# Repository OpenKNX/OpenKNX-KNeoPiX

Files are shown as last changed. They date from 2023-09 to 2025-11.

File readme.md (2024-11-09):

# OpenKNX - KNeoPix

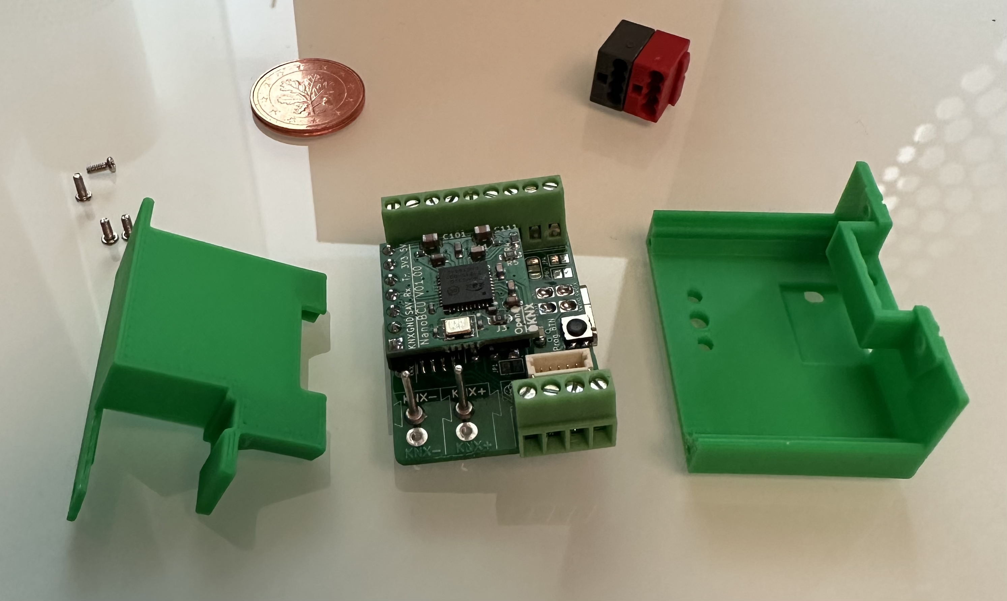
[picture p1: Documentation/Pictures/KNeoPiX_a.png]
KNEOPIX


## Preliminary Information about OpenKNX KNeoPix

The **OpenKNX KNeoPix** is a hardware solution designed specifically for DIY (Do It Yourself) projects in the realm of building automation and intelligent networking. Created for enthusiasts and hobbyists, it allows users to develop creative KNX automation solutions. **KNeoPix** is a DIY product and does not come with any warranties. This means that users are responsible for assembly, configuration, and operation. **KNeoPix** is fully compatible with the **openKNX** software platform, ensuring seamless integration within the **OpenKNX** ecosystem.

Additionally, **KNeoPix** supports LED control, including **WS2815**, **SM16704**, and **SK6812** addressable LEDs, with voltage ranges from **3.3V to 24V**. Two isolated IOs are dedicated for this LED control, allowing for smooth management of lighting systems. Moreover, **6 direct IOs** are available for additional control purposes, making **KNeoPix** a versatile solution for various applications in building automation.

KNEOPIX

### Hardware

The hardware of **KNeoPix** is based on either the [XIAO RP2040](https://www.seeedstudio.com/XIAO-RP2040-v1-0-p-5026.html) or the [XIAO SAMD21](https://www.seeedstudio.com/Seeeduino-XIAO-Arduino-Microcontroller-SAMD21-Cortex-M0+-p-4426.html) microcontroller. It works in conjunction with the [OpenKNX BCU](https://github.com/OpenKNX/OpenKNX/wiki/NanoBCU) platform, enabling a broad range of applications in building KNX automation and smart home networking.

### Power Supply

A standout feature of **KNeoPix** is its flexible power supply options. It can be powered directly from the **KNX bus voltage** at either **3.3V** or **5V**, facilitating straightforward integration into KNX-based systems. Additionally, it can be powered via an external voltage source ranging from **6V to 24V**. This flexibility allows **KNeoPix** to accommodate a wide variety of installation scenarios and adapt to diverse system requirements.

### Galvanic Isolation

When powered by an external voltage source, **KNeoPix** offers **galvanic isolation** from the KNX bus. This feature ensures a safe and reliable integration into KNX networks by protecting against electrical disturbances, enhancing overall system stability.

### Inputs and Outputs (I/Os)

**KNeoPix** provides a total of **6 direct** and **2 isolated** inputs and outputs (I/Os), offering versatile application possibilities. Its primary function is to control **RGB LEDs** via the two isolated I/Os, enabling captivating lighting effects for smart buildings. The six direct I/Os can be used for additional control tasks, making **KNeoPix** an incredibly flexible tool for various building automation purposes.

### Voltage Options

**KNeoPix** supports multiple voltage configurations, operating both the external voltage at **3.3V/5V** as a direct power supply, or using **6V to 24V** as a variable power supply. This provides maximum flexibility in configuring and deploying the hardware to meet specific project requirements.

### Pin Compatibility

Another key feature of **KNeoPix** is its **pin compatibility** with other microcontrollers in the **XIAO series**, such as the [XIAO ESP32C3](https://www.seeedstudio.com/Seeed-XIAO-ESP32C3-p-5431.html) and [XIAO ESP32S3](https://www.seeedstudio.com/XIAO-ESP32S3-p-5627.html). This compatibility enhances its versatility, allowing users to take advantage of existing hardware for their projects and easily integrate with other XIAO boards.

## KNeoPiX Documentation

This documentation provides details about the KNeoPiX board and its components, including jumper settings, connections, power source options, and other related information.

### Available IOs and Descriptions i.e. for XIAO RP2040 and SAMD21

|  **IO Number**  | **<a href="Documentation/External/XIAO_RP2040_v1/XIAO RP2040 v1.22 SCH.pdf" target="_blank">XIAO RP2040 Pins</a>** | **<a href="Documentation/External/XIAO-SAMD21_V1/Seeeduino XIAO_v1.0_SCH_191112.pdf" target="_blank">SAMD21 Pins</a>** | **Description** |
| :---: | :--- | :--- | :--- |
| D0** | GPIO0 / A0 | GPIO0 / A0 | **Non-isolated IO - Prog Button** |
| **D1** | GPIO1 / A1 | GPIO1 / A1 | **Non-isolated IO** |
| **D2** | GPIO2 / A2 | GPIO2 / A2 | **Non-isolated IO** |
| **D3** | GPIO3 / A3 | GPIO3 / A3 | **Non-isolated IO** |
| **D4** | GPIO4 / SDA | GPIO4 / SDA | **Isolated IO - NEO DATA0 OUT** |
| **D5** | GPIO5 / SCL | GPIO5 / SCL | **Isolated IO - NEO DATA1 OUT** |
| **D6** | GPIO6 / TX | GPIO6 / TX | **Isolated IO - to KNX RX** |
| **D7** | GPIO7 / RX | GPIO7 / RX | **Isolated IO - to KNX TX** |
| **D8** | GPIO8 / SCK | GPIO8 / SCK | **Non-isolated IO** |
| **D9** | GPIO9 / MISO | GPIO9 / MISO | **Non-isolated IO** |
| **D10** | GPI010 / MOSI | GPI010 / MOSI | **Non-isolated IO** |
| **OnBoard LED** | GPIO25 / RGB BLUE | GPIO11 / BLUE | **USER LED** |
| **OnBoard LED** | GPIO16 / RGB GREEN | GPIO12 / BLUE | **USER LED** |
| **OnBoard LED** | GPIO17 / RGB RED | GPIO13 / YELLOW | **USER LED** |
| NEOPIXEL | GPIO12 / RGB NEOPIXEL (GPIO11 / POWER) | N/A | **Onboard NEOPIXEL RGB LED** |
| **SWD** | SWDIO, SWCLK, RST | SWDIO, SWCLK, RST | **Debugging Interface** |
| **Prog Button** | GPIO26 (RUN) | PA15 (RUN) | **Program Button Interface** |

### 1. KNX Connection and Isolator

The KNX connection and isolator section manages communication with the KNX bus. The relevant components in this section include:

- **KNX+**: KNX positive voltage input.
- **KNX-**: KNX negative voltage input.
- **GN1**: KNX communication ground.
- **ISO_IN** / **ISO_OUT**: Isolated I/O pins for communication between the KNX module and the rest of the circuit.

### 2. Digital Isolator for GPIO4 & GPIO5

This section uses the **ADuM1250** IC to isolate GPIO pins 4 and 5. The jumpers associated with this section are:

- **R1, R2**: 0 Ohm jumpers.
- **C4**: Capacitor for filtering.
- **ISO_DATA_OUT**: Isolated data output.
- **ISO_DATA_IN**: Isolated data input.

### 3. Connections

#### 3.1 Screw Terminal - Isolated I/Os

- Provides isolated input/output connections.
- **J4**: Terminal block for isolated I/O pins.

#### 3.2 Screw Terminal - Non-Isolated I/Os

- For non-isolated communication.
- **J3**: Terminal block for non-isolated I/Os.

#### 3.3 Prog Button

- **SW1**: Programming button to interact with the microcontroller.

#### 3.4 OpenKNX Debug

- Debug connections to monitor KNX communication signals.

### 4. Jumpers - Power Source Selection

#### 4.1 JP1 (GND KNX Voltage Input)

- Jumper for KNX GND voltage input.

#### 4.2 JP2 (3V3 KNX Voltage Input)

- Jumper to select **3.3V** KNX voltage input.

#### 4.3 JP5 (Select U2 and Input Voltage)

- Jumper to select voltage source:
  - **Bridge 1+2** for **3V3**.
  - **Bridge 2+3** for **5V**.

#### 4.4 JP6 (5V KNX Voltage Input)

- Jumper for **5V** KNX voltage input.

### 5. External VCC Input

The external VCC input allows the board to be powered by an external DC power source (6-24V).

- **JP3**: Select between **3.3V** or **5V** input from external power.
- **U2 (LM2937IMP-3.3/5.0)**: Regulator to convert external voltage to either **3.3V** or **5V**.
- **JP5**: Used to select the desired output voltage.
  - **Bridge 1+2** for **3.3V** output.
  - **Bridge 2+3** for **5V** output.

### 7. Material

- KNeoPix PCB can be Ordered from the [OpenKNX-Community](https://github.com/OpenKNX/OpenKNX/wiki/Device-Overview) or you can manufacture (i.e.: [jlcpcb.com](https://jlcpcb.com/https:/) ) your own PCB using the BOM/CPL and GERBER from [Release Folder](Hardware/Release/v1.3/)

  | Kommentar                         | Designator    | Footprint                                                                                |
  | ----------------------------------- | --------------- | ------------------------------------------------------------------------------------------ |
  | 100nF                             | C1,C2, C5, C6 | C 0805 2012 Metric                                                                       |
  | 100nF 25V                         | C3            | C_0805 2012 Metric                                                                       |
  | 10µf 16V                         | C4            | C 0805 2012 Metric                                                                       |
  | OpenKNX_BCU                       | GN1           | [NanoBCU](https://github.com/OpenKNX/OpenKNX/wiki/NanoBCU) (Optional: LowProfile )       |
  | ADuM1201AR / ADum1250             | U3            | SOIC-8 3.9x4.9mm P1.27mm                                                                 |
  | Prog BTN                          | SW1           | SW Push 1P1T NO CK KMR2                                                                  |
  | Seeeduino XIAO                    | U1            | [Seeeduino XIAO](https://www.seeedstudio.com/xiao-series-page) (Tested: RP2040 / SAMD21) |
  | LM2937IMP-3.3 / 5.0               | U2 - Optional | SOT-223-3 Tab Pin2                                                                       |
  | ADum1250                          | U4 - Optional | SOIC-8 3.9x4.9mm P1.27mm                                                                 |
  | SMAJ40CA-13-F                     | D3 - Optional | D_SMA                                                                                    |
  | Screw Terminal - Isolated IOs     | J4 - Optional | Terminal Block Phoenix MPT-0,5-4-2.54 1x04 P2.54mm Horizontal                            |
  | Screw Terminal - Non Isolated IOs | J3 - Optional | TerminalBlock Phoenix MPT-0,5-9-2.54 1x09 P2.54mm Horizontal                             |
  | Conn_01x05                        | J5 - Optional | JST SH BM05B-SRSS-TB 1x05-1MP P1.00mm Vertical                                           |
  | Conn_01x05                        | J6 - Optional | PinHeader 1x05 P1.00mm Vertical                                                          |

The [Schematic](/Documentation/Schematic_v1.3.pdf) provides all related and also additional Informations!

### 8. Soldering

The final soldering targets (Designators) are all documented on the PCB. You must align the board with solder pads from XIAO to ensure that the board is properly aligned with XIAO.
It is best to use the markings provided for this purpose and the solder pap holes, which can then be seen on the top of the circuit board. It is best to use an adhesive strip to fix the circuit board and XIAO in place.

- Soldering sequence: Start with the smallest components (SMD Capacitors, ICs, passivce throuch-hole, connectors, transsistors, ...)
  Here the Soldering Example, from left to right.

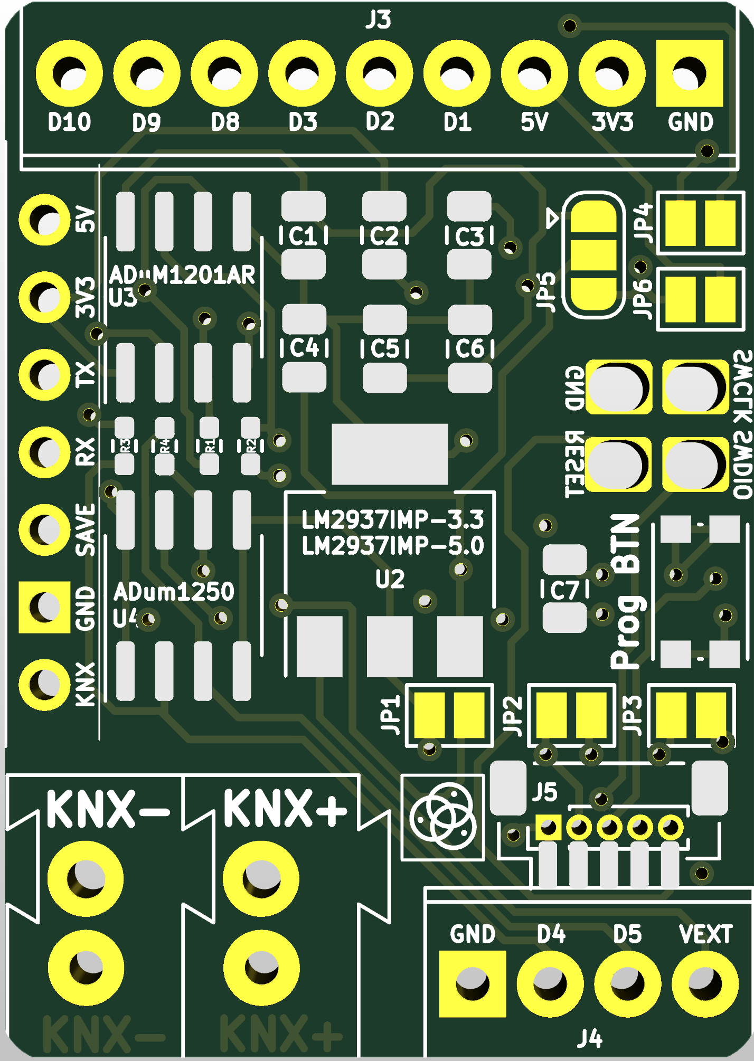
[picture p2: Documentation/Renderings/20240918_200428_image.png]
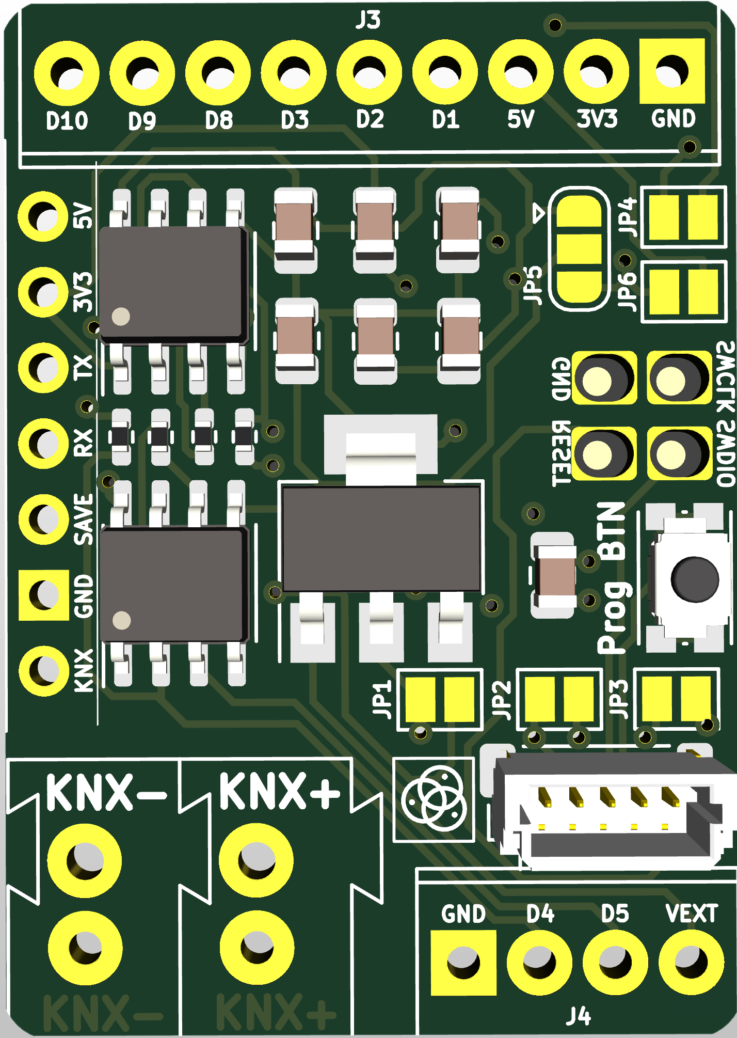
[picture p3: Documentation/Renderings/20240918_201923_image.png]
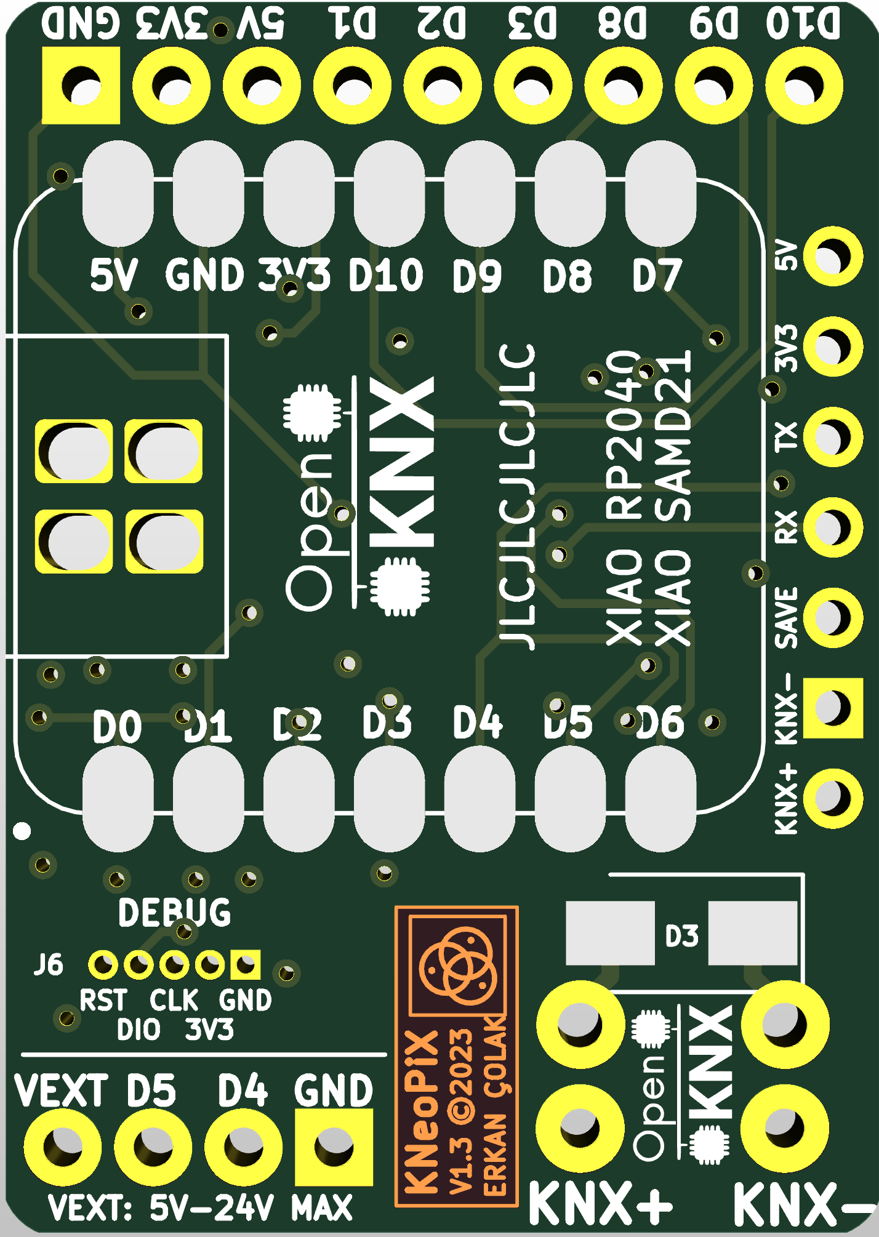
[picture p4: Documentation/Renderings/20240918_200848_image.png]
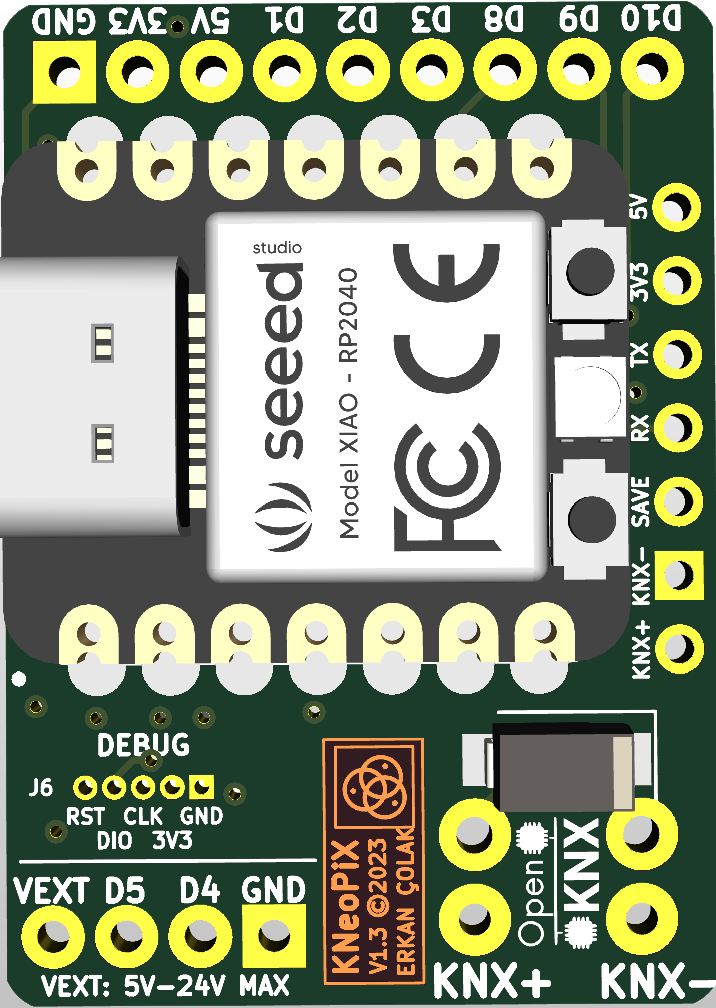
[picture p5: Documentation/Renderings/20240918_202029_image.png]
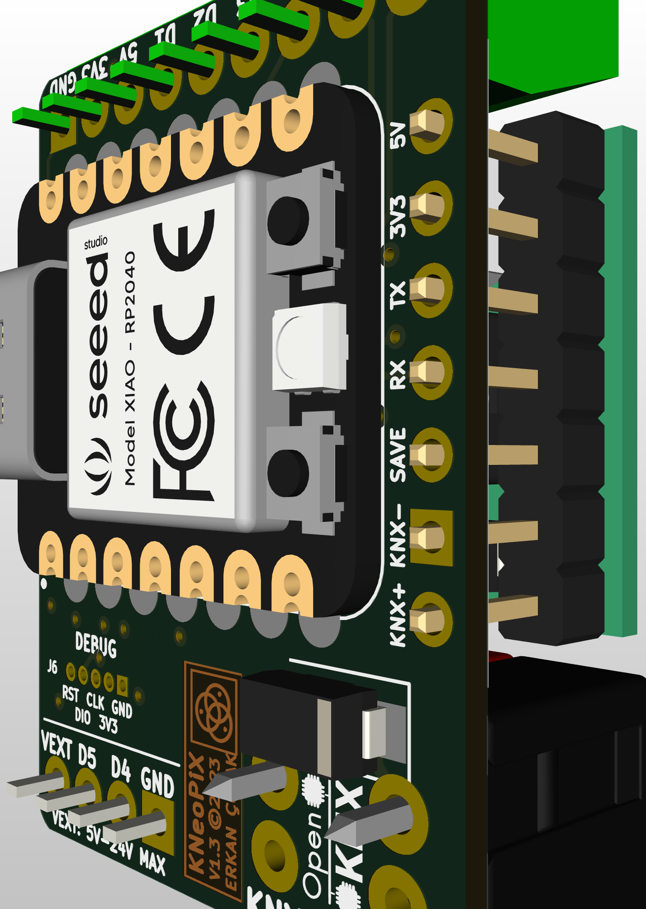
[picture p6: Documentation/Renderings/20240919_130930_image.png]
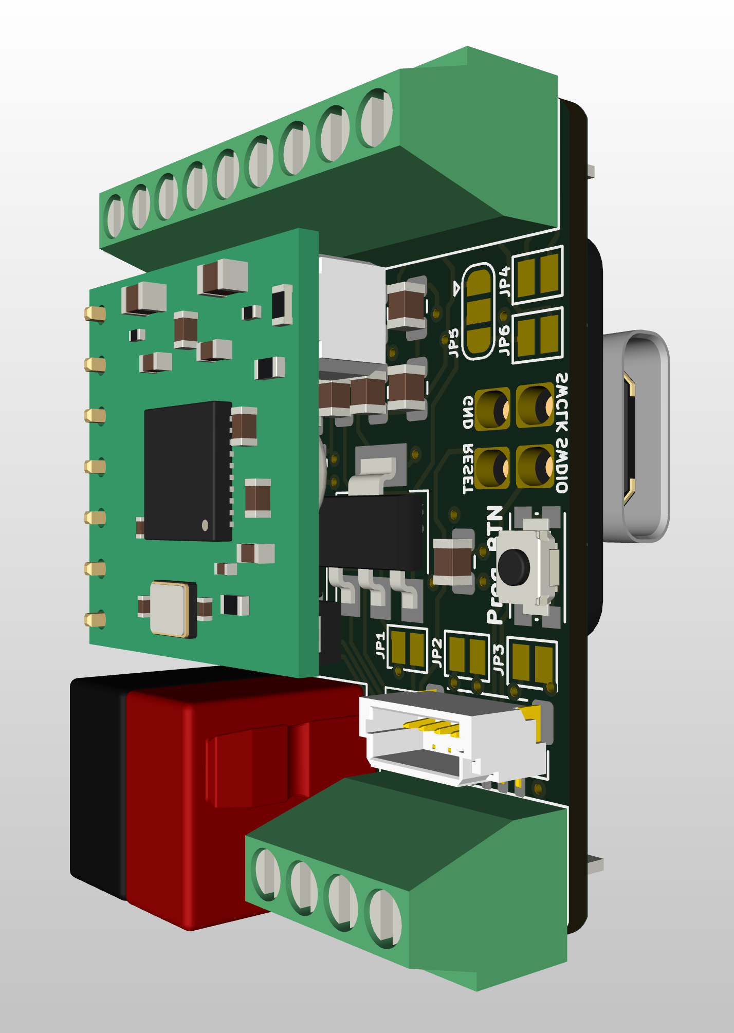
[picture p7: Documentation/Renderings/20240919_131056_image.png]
  -      
  - To solder the debug interface connections, you should solder the designated holes. Be careful not to create any solder bridges between RESET, GND, SWDIO, and SWCLK. These connections are optional.

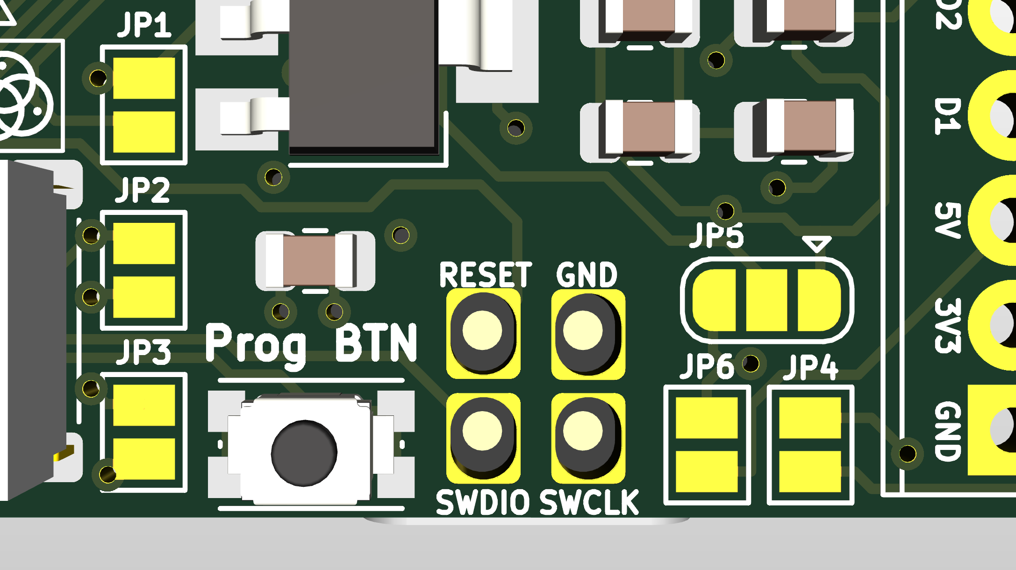
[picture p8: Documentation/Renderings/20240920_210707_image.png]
    
- Finish by soldering larger components ( screw terminals).
- Check all solder joints for proper connections and make sure no short circuits are present.

### 9. Jumper Soldering / Power Source Selection Guide

| **Use Case** | **Jumpers to Bridge** | **Additional Information** |
| --- | --- | --- |
| **KNX 3V3 ONLY** | JP1 → Bridge JP2 → Bridge | JP3 → Bridge possible JP5 → Bridge 1+2 (3V3) possible |
| **KNX 5V ONLY** | JP1 → Bridge JP6 → Bridge | JP3 → Bridge possible JP5 → Bridge 2+3 (5V) possible |
| **External 3V3 ONLY** | JP5 → Bridge 1+2 (3V3) | **Do NOT Bridge:** JP1/JP2/JP3 |
| **External 5V ONLY** | JP5 → Bridge 2+3 (5V) | **Do NOT Bridge:** JP1/JP2/JP3 |
| **EXTERNAL VCC IN (6–24V)** | JP5 → Bridge 1+2 (for 3.3V output) | LM2937IMP–3.3 out is 3V3 |
| | JP5 → Bridge 2+3 (for 5V output) | LM2937IMP–5.0 out is 5V |
| **EXTERNAL VCC IN is 3V3** | JP3 → Bridge JP2 → Bridge | Be careful! Selected Voltage must fit the Jumper Settings. |
| **EXTERNAL VCC IN is 5V** | JP3 → Bridge JP6 → Bridge | |
| **EXTERNAL VCC IN to OUT (Special Case)** | JP3 → Bridge (for 5V or 3V3) | External VCC will be used as OUT!**ONLY** use **KNX VCC ONLY** |
| **Special Case** | JP5 → Bridge for selected EXT_VCC_IN | Use delivered KNX VCC without external power source |

**Note:** For **EXTERNAL VCC** input, you need to solder components U2, C3, C4.

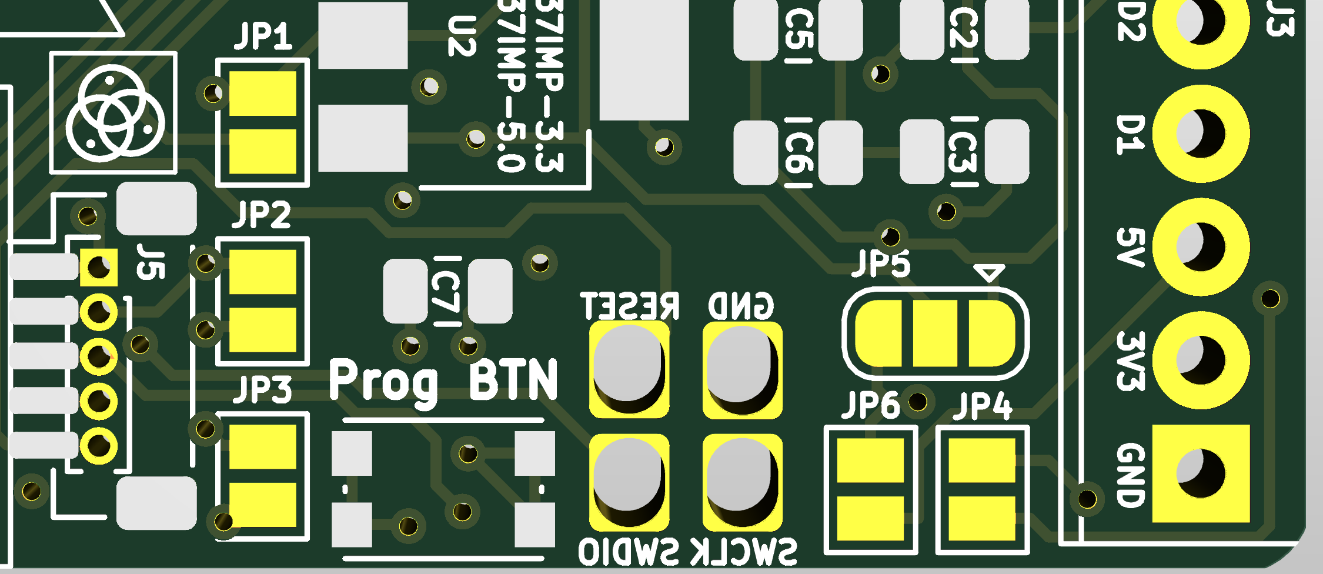
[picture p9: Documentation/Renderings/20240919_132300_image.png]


- **For External VCC Input**: Ensure that U2, C3, and C4 are soldered.
- **Power Source Selection**: Always double-check the jumper settings before powering the board to avoid damaging components.

---

## 9. Enclosure / Case

The **KNeoPix** enclosure consists of two parts and is available as an **STL file**. You can print it with your own 3D printer or through a service like **JLCPCB**. I recommend using **PETG** material for its durability and heat resistance, but you’re free to choose any material that fits your needs.

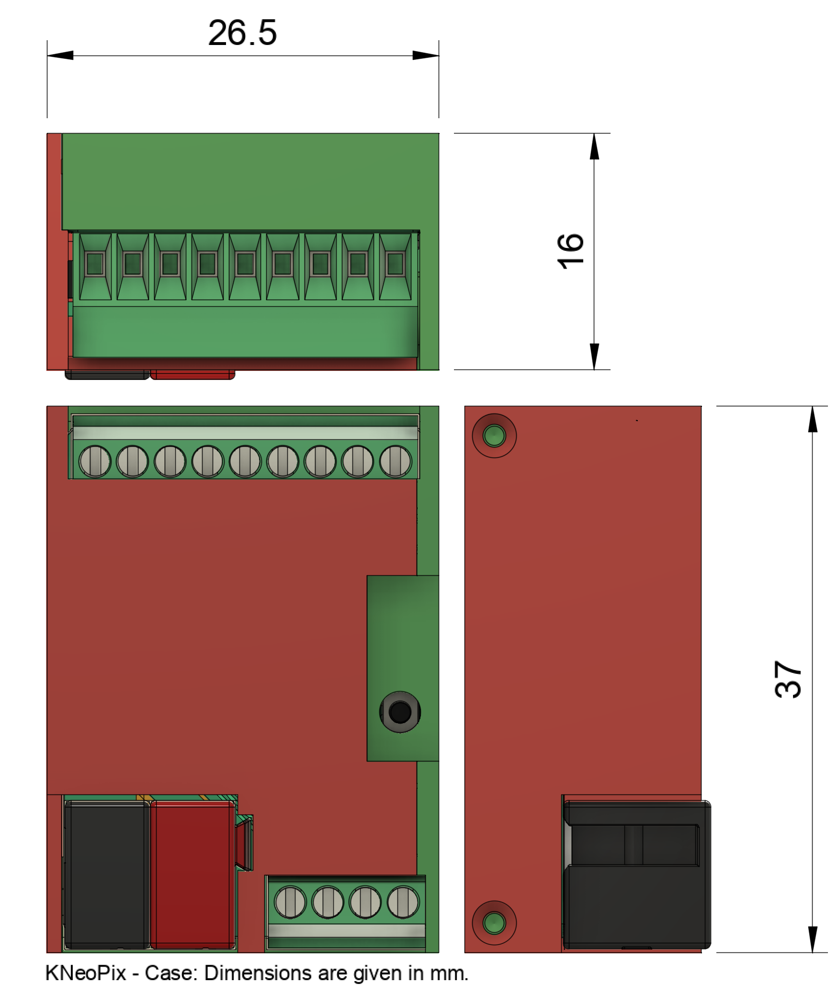
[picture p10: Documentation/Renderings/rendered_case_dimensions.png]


The enclosure is designed to fit the fully assembled PCB perfectly. Only **four screws** are needed to secure everything.

**The assembly process is as follows:**

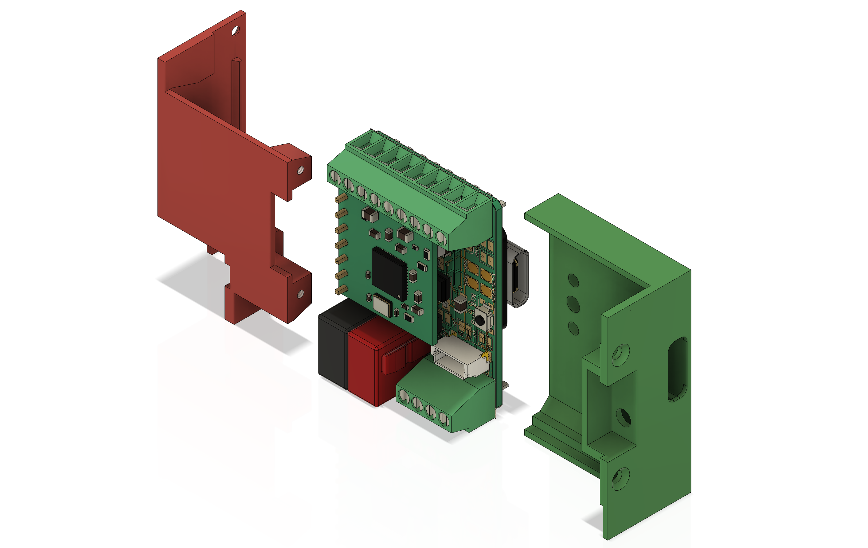
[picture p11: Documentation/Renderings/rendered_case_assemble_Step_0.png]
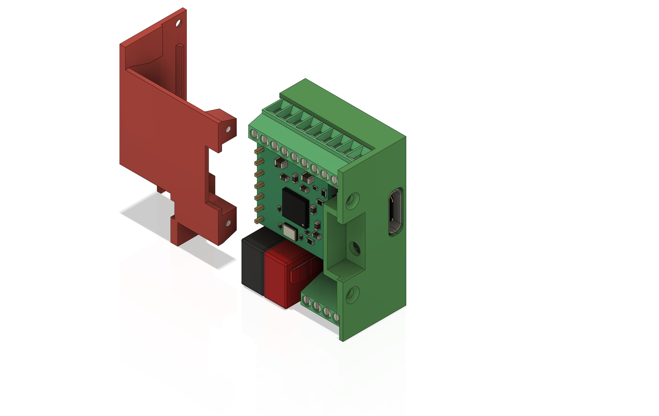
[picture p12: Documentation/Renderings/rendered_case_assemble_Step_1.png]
  
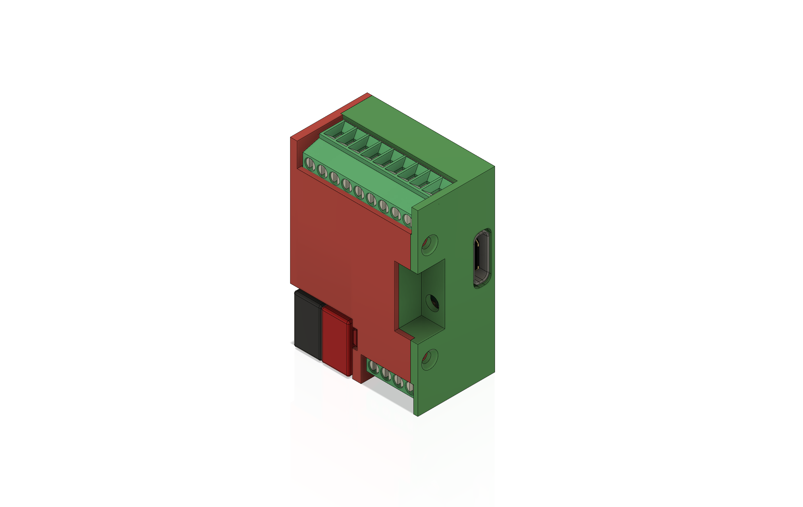
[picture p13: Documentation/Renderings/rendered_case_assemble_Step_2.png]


1. **Insert the PCB**: Slide the PCB into the case, starting with the **USB-C port** into its dedicated slot.
2. **Attach the cover**: Once the PCB is in place, insert and secure the top cover.
3. **Fit the KNX terminal**: After assembly, the KNX terminal will align perfectly.

The enclosure has two openings:

- One on the **top** for the **Prog button**.
- One on the **bottom**, depending on whether you’re using the **ESP**, **RP2040**, or **SAMD21** version of the **XIAO**, for the **Boot** and **Reset buttons**, as well as the **LEDs**.

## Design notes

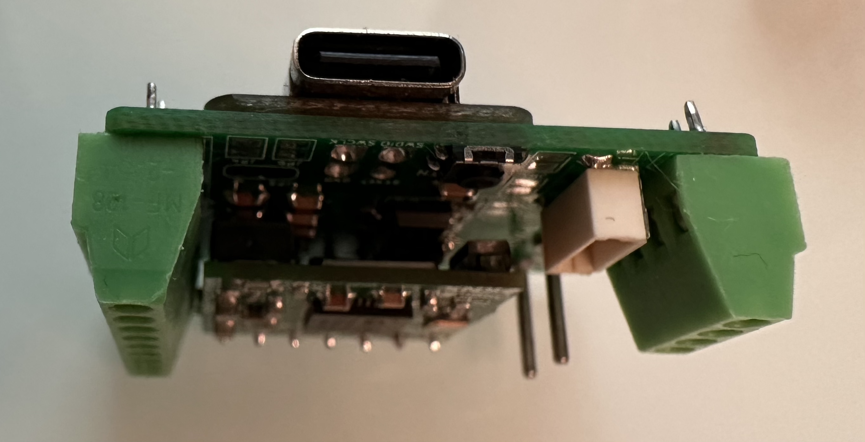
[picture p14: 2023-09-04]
Documentation/Pictures/KNeoPiX_9.png

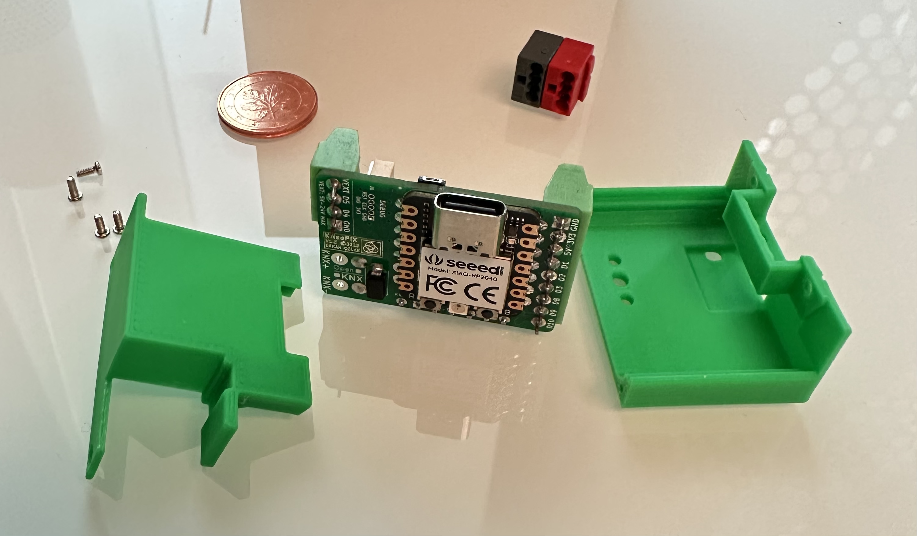
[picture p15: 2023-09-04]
Documentation/Pictures/KNeoPiX_b.png

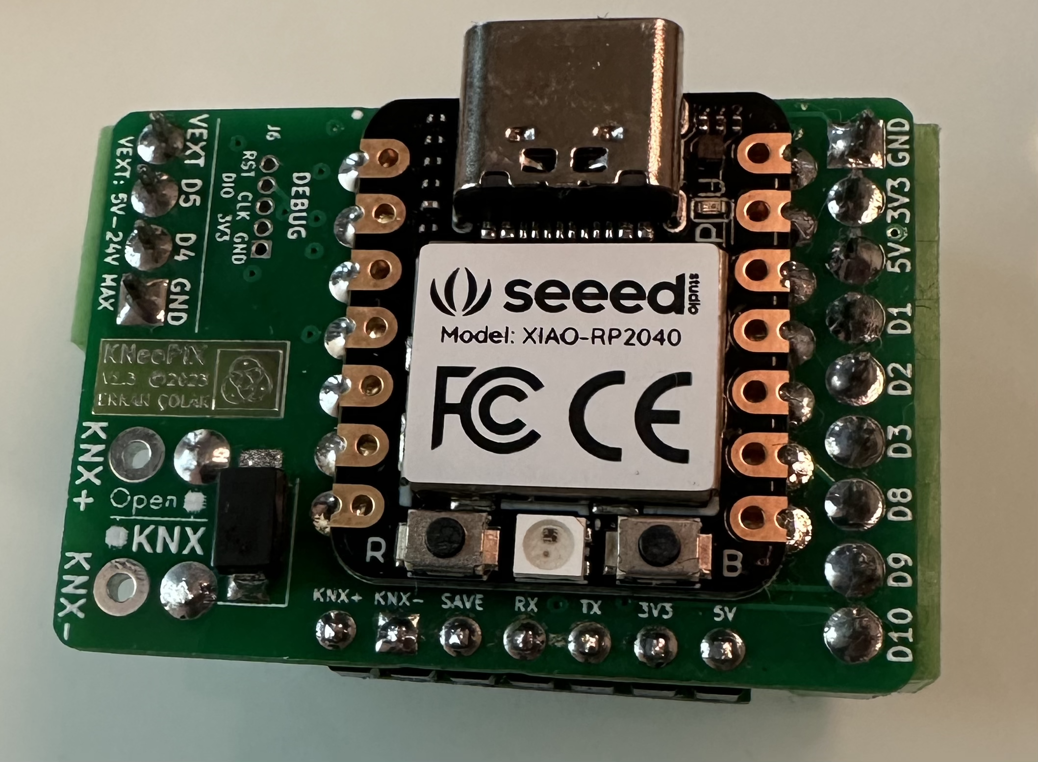
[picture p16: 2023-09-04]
Documentation/Pictures/KNeoPiX_8.png

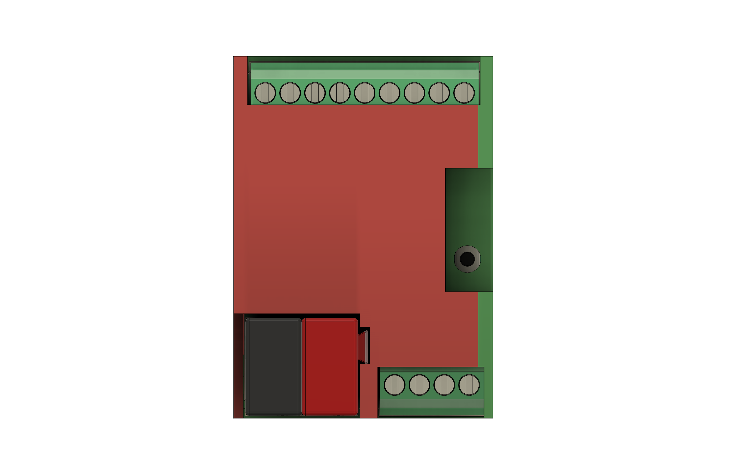
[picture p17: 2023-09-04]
Documentation/Renderings/rendered_case_top.png

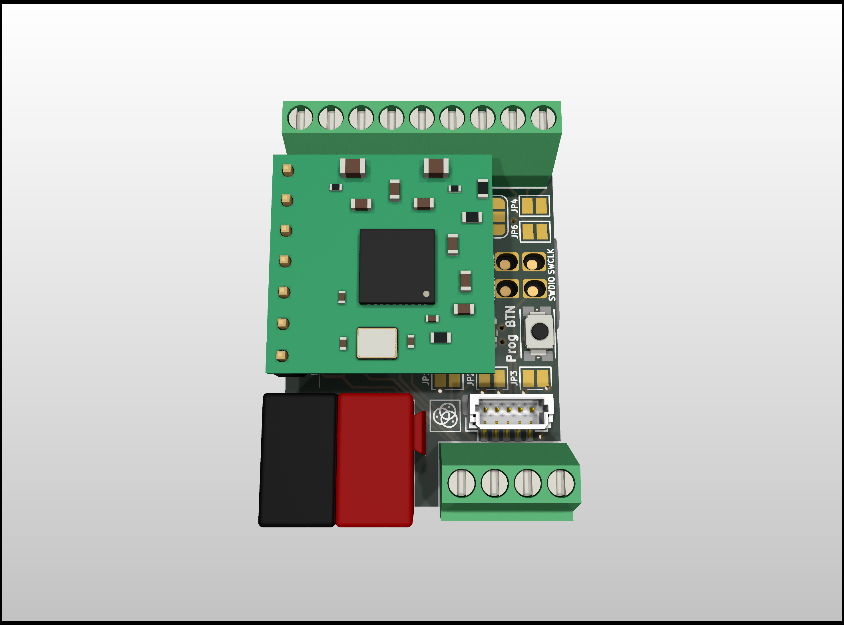
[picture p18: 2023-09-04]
Documentation/Renderings/rendered_pcb_top.png

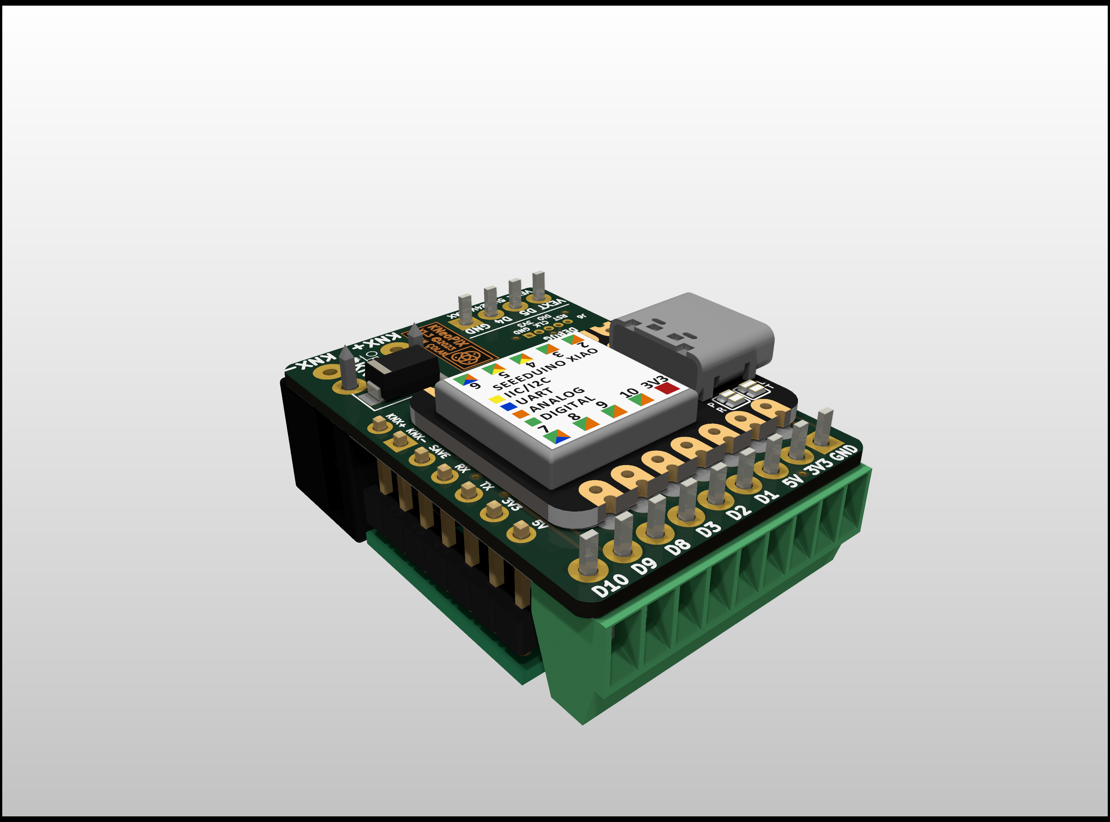
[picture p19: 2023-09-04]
Documentation/Renderings/rendered_pcb_r_back_samd21.png

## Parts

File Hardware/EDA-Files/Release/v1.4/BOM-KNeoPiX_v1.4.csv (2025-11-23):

Comment | Designator | Footprint | LCSC | Quantity
100nF/16v | C1,C2,C3,C4,C5 | C_01005_0402Metric | C60474 | 5
100nF/50v | C8 | C_0805_2012Metric | C5137467 | 1
10uf/50V | C6,C7 | C_0805_2012Metric | C2932476 | 2
22uf/16V | C10,C9 | C_0805_2012Metric | C98190 | 2
ADUM1250ARZ-RL7 - (ADuM1201AR / ADum1250AR) AR suffix required | U3 | SOIC-8_3.9x4.9mm_P1.27mm | C13839 | 1
AP63205WU-7 | U5 | TSOT-26_L2.9-W1.6-P0.95-LS2.8-BL | C2071056 | 1
CR5040-4R7M | L1 | IND-SMD_L5.0-W5.0 | C520348 | 1
DIODE SCHOTTKY 40V SOD-323HE | D1,D2 | SOD-323_L1.7-W1.3-LS2.6-RD-1 | C172430 | 2
PROG BUTTON | SW1 | KEY-SMD_4P-L4.2-W3.2-P2.20-LS4.6 | C139797 | 1
TXS0108EPWR | U2 | TSSOP-20_L6.5-W4.4-P0.65-LS6.4-BL | C17206 | 1
~ | J5 | JST_SH_BM05B-SRSS-TB_1x05-1MP_P1.00mm_Vertical | C160391 | 1
243-131 | H2 | 243131 |  | 1
Screw Terminal - Isolated IOs | J4 | TerminalBlock_Phoenix_MPT-0,5-4-2.54_1x04_P2.54mm_Horizontal |  | 1
Screw Terminal - Isolated IOs | J3 | TerminalBlock_Phoenix_MPT-0,5-9-2.54_1x09_P2.54mm_Horizontal |  | 1
243-131 | H1 | 243131 |  | 1
SolderJumper_3_Bridged12 | JP5 | SolderJumper-3_P1.3mm_Bridged2Bar12_Pad1.0x1.5mm |  | 1

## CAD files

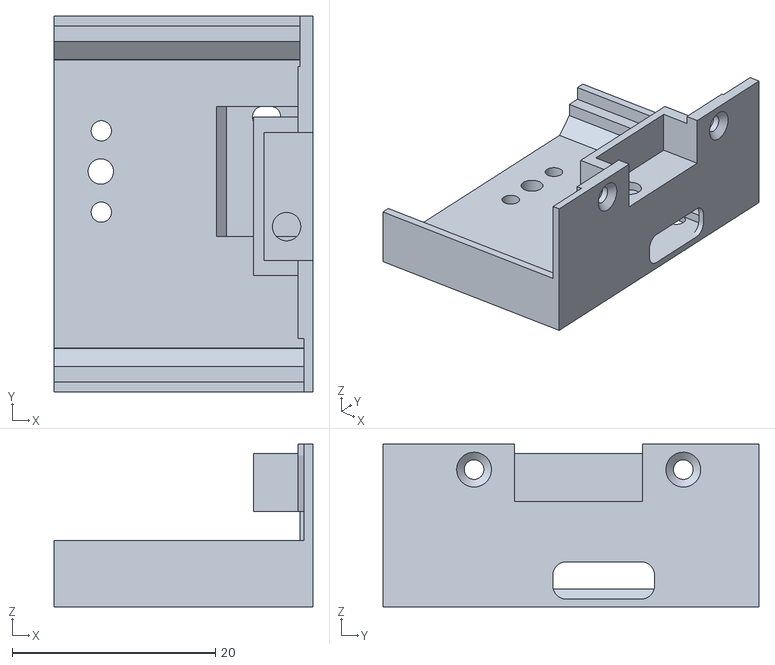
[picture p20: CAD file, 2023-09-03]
Hardware/CAD-Files/Release/Case-Gehäuse_rp2040.stl
25.5 x 37.0 x 16.0

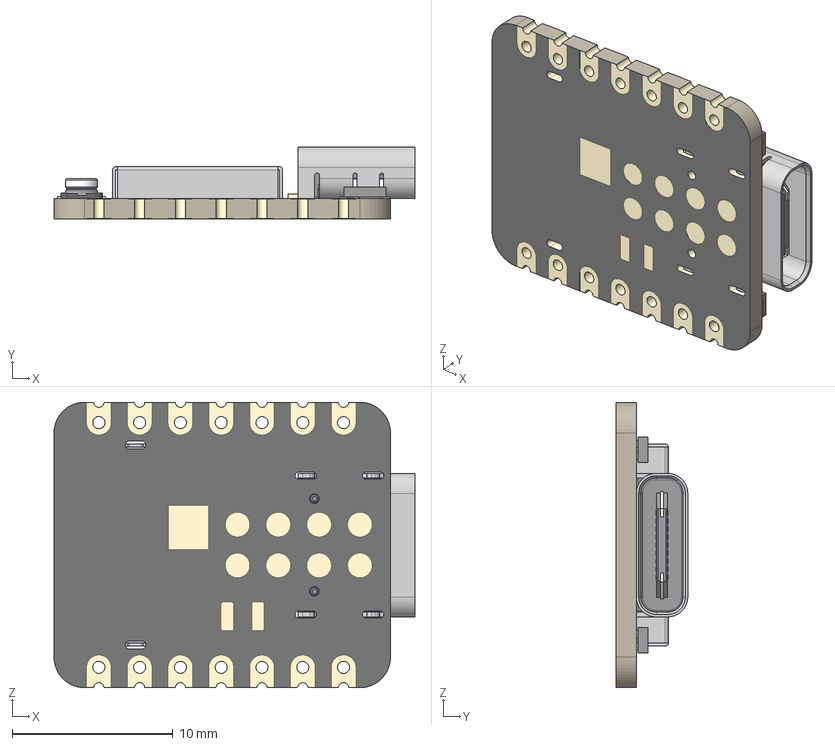
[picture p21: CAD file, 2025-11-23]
Hardware/EDA-Files/Source/KNeoPix.3D-Models/XIAO-ESP32S3 v2.step
22.5 x 4.46 x 17.8 mm
BOSS-EXTRUDE14_8_
BOSS-EXTRUDE7_4_
BOSS-EXTRUDE7_3_
BOSS-EXTRUDE14_4_
BOSS-EXTRUDE14_2_
BOSS-EXTRUDE14_11_
BOSS-EXTRUDE7_7_
BOSS-EXTRUDE14_9_
BOSS-EXTRUDE14_3_
BOSS-EXTRUDE14_7_
MIRROR2
BOSS-EXTRUDE14_5_
BOSS-EXTRUDE14_12_
BOSS-EXTRUDE7_8_
BOSS-EXTRUDE7_1_
BOSS-EXTRUDE14_10_
BOSS-EXTRUDE7_9_
BOSS-EXTRUDE14_6_
BOSS-EXTRUDE14_1_
BOSS-EXTRUDE7_6_
BOSS-EXTRUDE7_2_
CUT-EXTRUDE5
BOSS-EXTRUDE7_5_
Shield
Pins x 2
U.FL-R-SMT-1_10_ v1

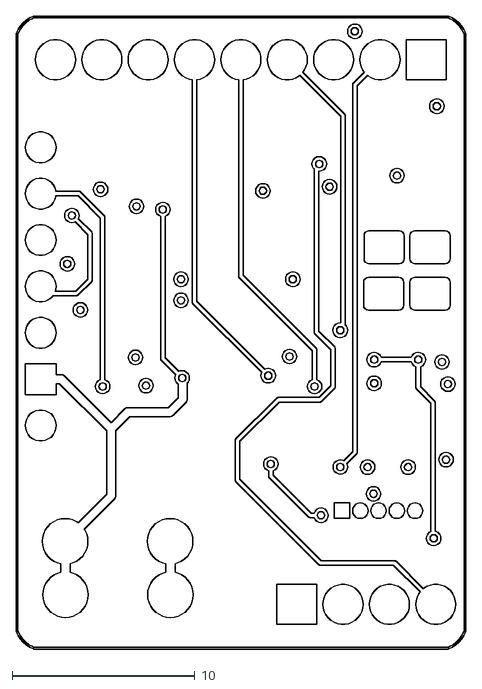
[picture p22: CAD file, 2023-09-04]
Hardware/EDA-Files/Source/Plot/DXF/KNeoPiX_v1.3-In2_Cu.dxf
24.6 x 34.7

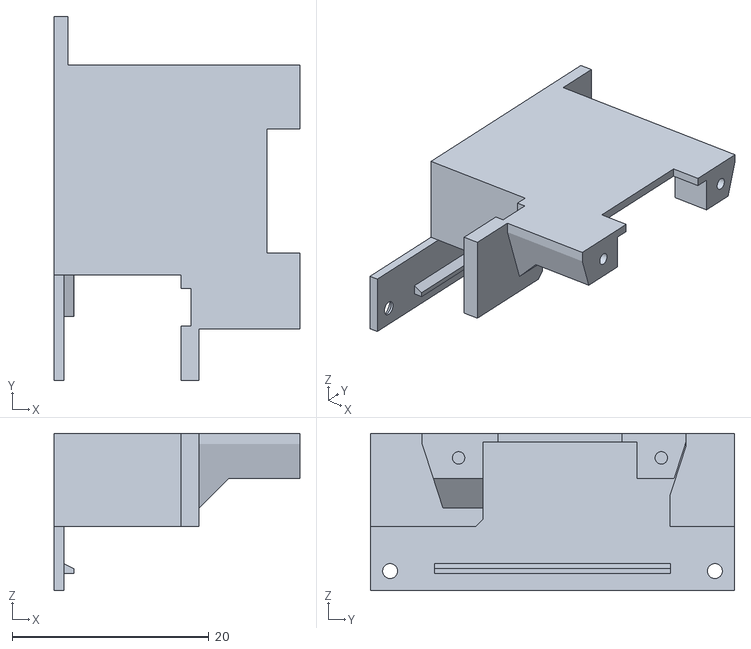
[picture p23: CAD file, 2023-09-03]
Hardware/CAD-Files/Release/Case-Deckel_rp2040.stl
25.0 x 37.0 x 16.0

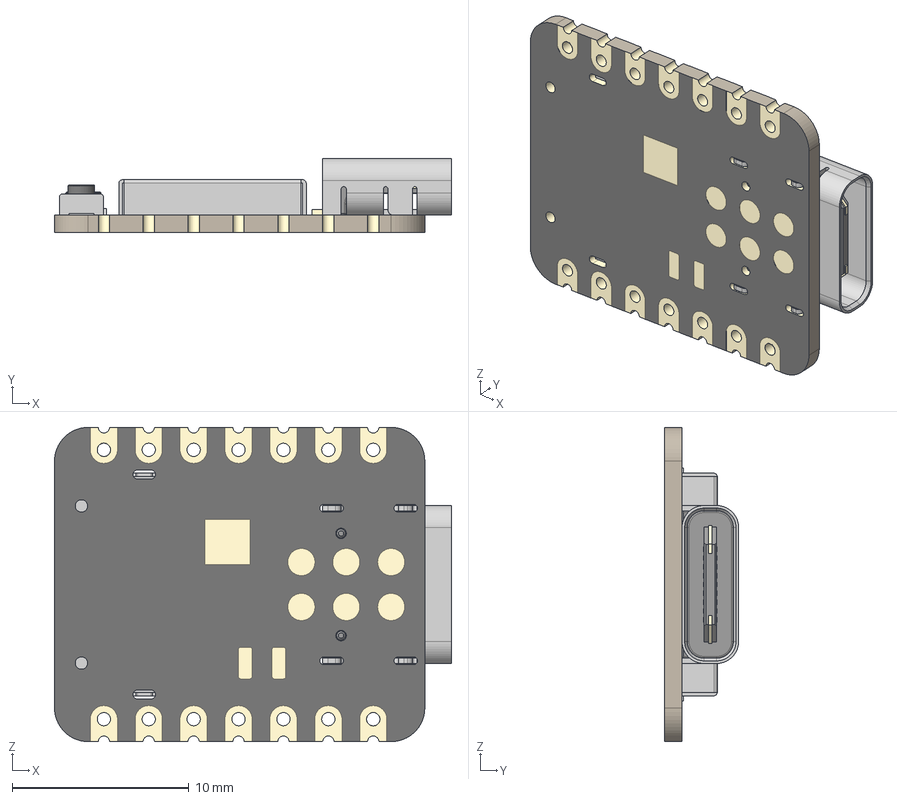
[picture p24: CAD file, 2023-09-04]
Hardware/EDA-Files/Source/KNeoPix.3D-Models/Seeed Studio XIAO-ESP32-C3.step
22.5 x 4.21 x 17.8 mm
BOSS-EXTRUDE14_8_
BOSS-EXTRUDE7_4_
BOSS-EXTRUDE7_3_
BOSS-EXTRUDE14_4_
BOSS-EXTRUDE14_2_
BOSS-EXTRUDE14_11_
BOSS-EXTRUDE7_7_
BOSS-EXTRUDE14_9_
BOSS-EXTRUDE14_3_
BOSS-EXTRUDE14_7_
MIRROR2
BOSS-EXTRUDE14_5_
BOSS-EXTRUDE14_12_
BOSS-EXTRUDE7_8_
BOSS-EXTRUDE7_1_
BOSS-EXTRUDE14_10_
BOSS-EXTRUDE7_9_
BOSS-EXTRUDE14_6_
BOSS-EXTRUDE14_1_
BOSS-EXTRUDE7_6_
BOSS-EXTRUDE7_2_
CUT-EXTRUDE5
BOSS-EXTRUDE7_5_
U.FL Connector v1
Button (1) x 2
Shield

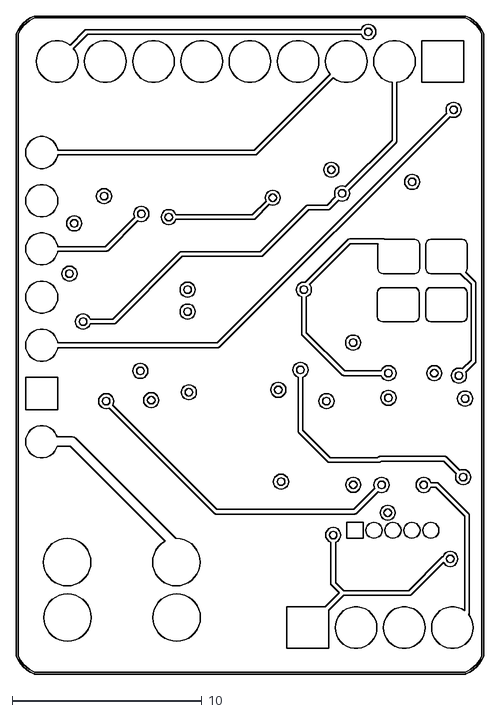
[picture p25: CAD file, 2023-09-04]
Hardware/EDA-Files/Source/Plot/DXF/KNeoPiX_v1.3-In1_Cu.dxf
24.6 x 34.7

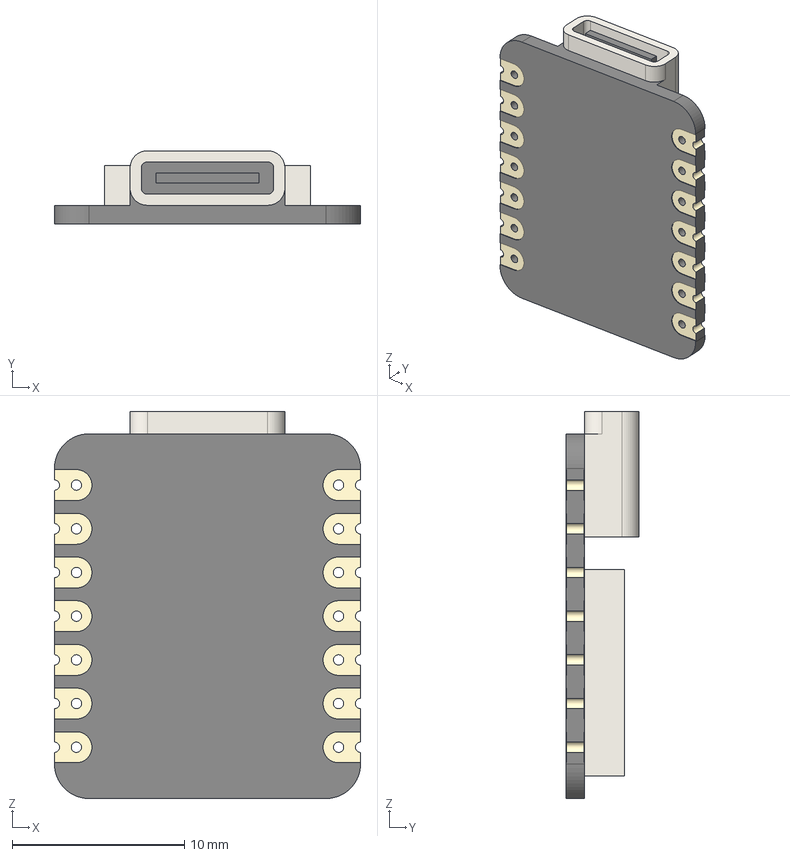
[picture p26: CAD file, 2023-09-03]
Hardware/EDA-Files/Source/KNeoPix.3D-Models/Seeeduino Xiao.step
17.8 x 4.27 x 22.5 mm

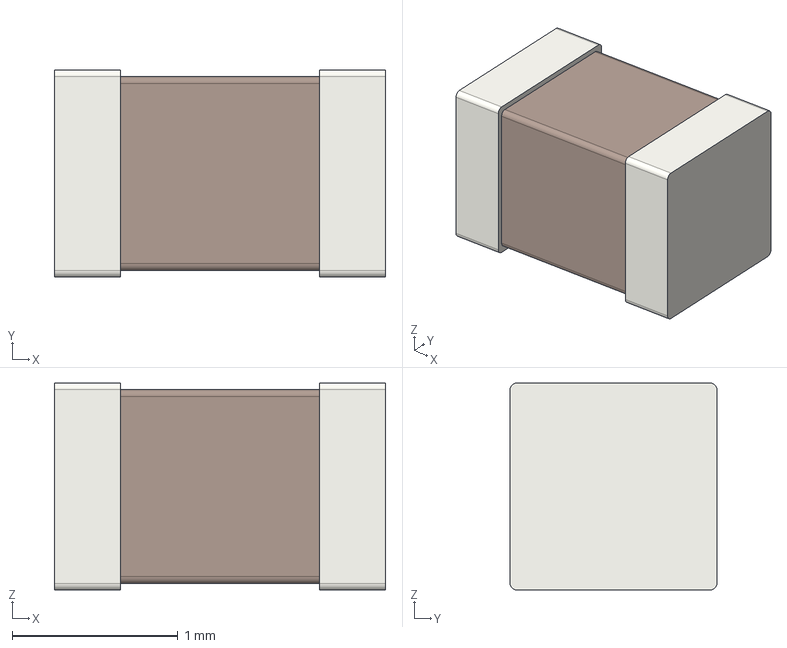
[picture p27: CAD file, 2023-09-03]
Hardware/EDA-Files/Source/KNeoPix.3D-Models/C_0805_2012Metric.step
2.00 x 1.25 x 1.25 mm

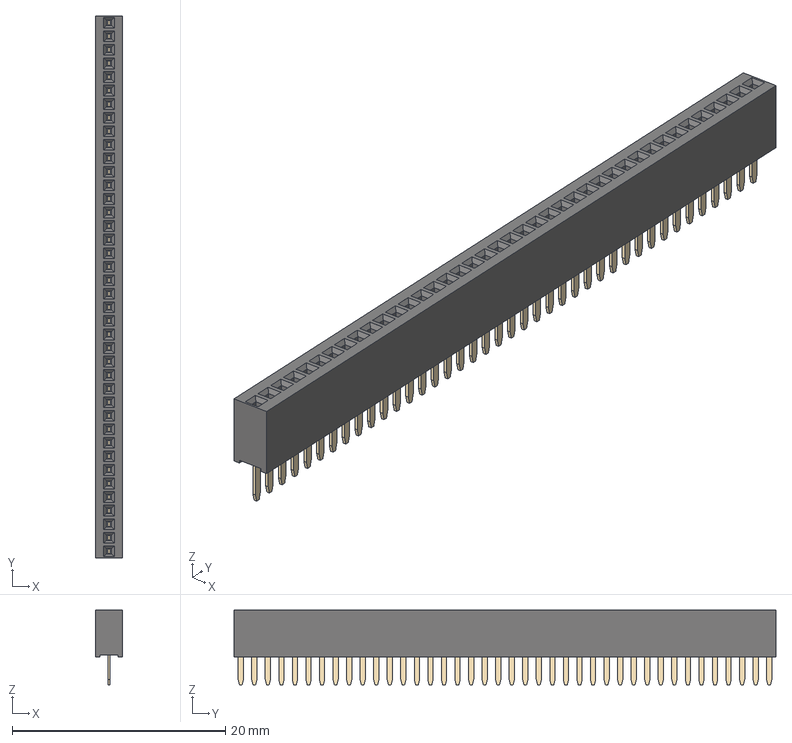
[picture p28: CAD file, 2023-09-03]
Hardware/EDA-Files/Source/KNeoPix.3D-Models/PinSocket_1x40_P1.27mm_Vertical.step
2.54 x 50.8 x 7.00 mm

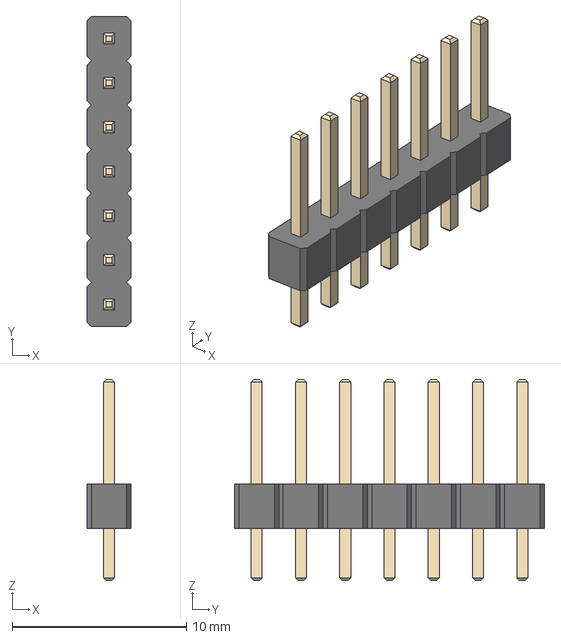
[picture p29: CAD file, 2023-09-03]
Hardware/EDA-Files/Source/KNeoPix.3D-Models/PinHeader_1x07_P2.54mm_Vertical.step
2.54 x 17.8 x 11.5 mm

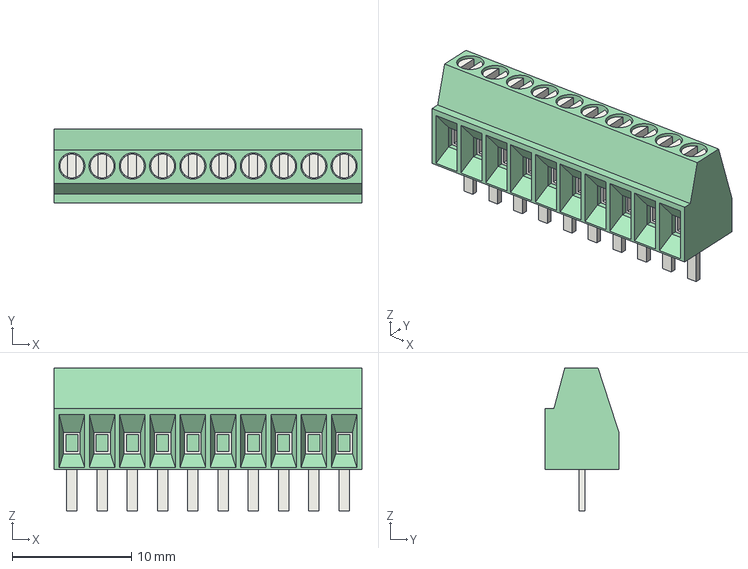
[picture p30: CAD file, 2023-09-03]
Hardware/EDA-Files/Source/KNeoPix.3D-Models/TerminalBlock_Phoenix_MPT-0,5-10-2.54_1x10_P2.54mm_Horizontal.step
25.9 x 6.20 x 12.0 mm

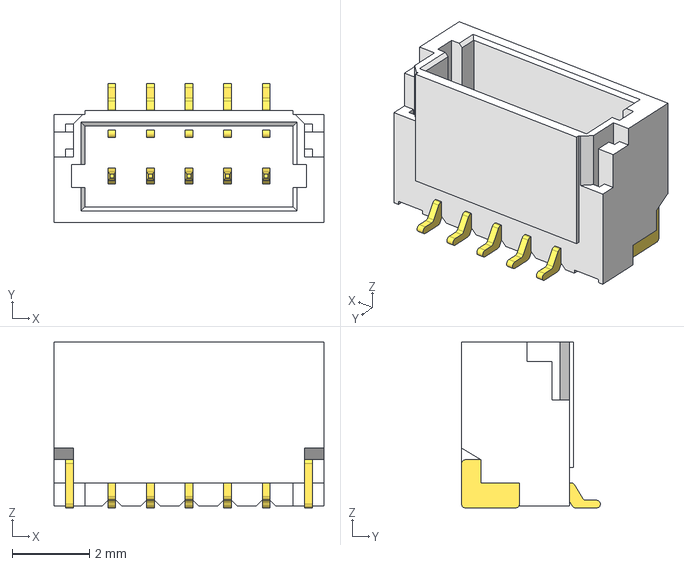
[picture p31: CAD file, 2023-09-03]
Hardware/EDA-Files/Source/KNeoPix.3D-Models/BM5B-SRSS-TB.step
7.00 x 3.60 x 4.30 mm

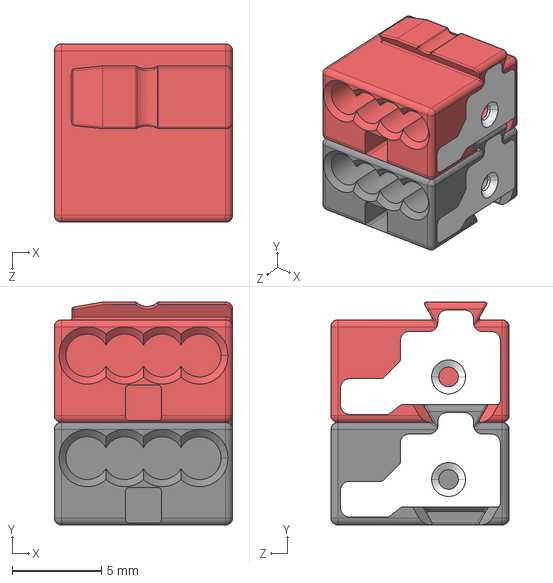
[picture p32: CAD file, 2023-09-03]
Hardware/EDA-Files/Source/KNeoPix.3D-Models/243-211--3DModel-STEP-56544.STEP
10.0 x 12.5 x 10.0 mm

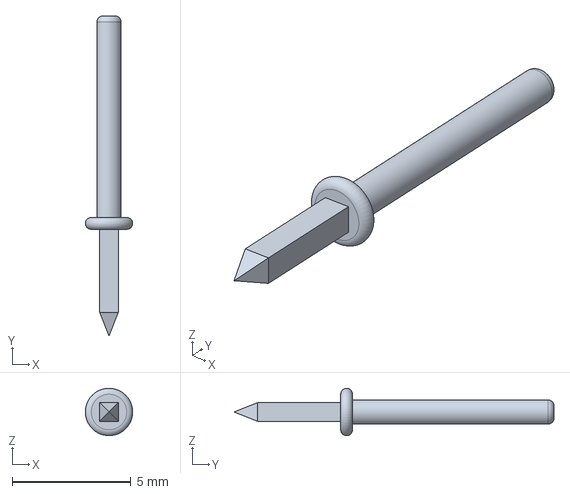
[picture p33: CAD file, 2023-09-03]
Hardware/EDA-Files/Source/KNeoPix.3D-Models/243-131.stp
2.00 x 13.5 x 2.00 mm

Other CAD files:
Hardware/CAD-Files/Source/Gehäuse_v0.32.step
Hardware/CAD-Files/Source/Deckel_v0.32.step
Hardware/EDA-Files/Source/KNeoPix.3D-Models/TerminalBlock_Phoenix_MPT-0,5-4-2.54_1x04_P2.54mm_Horizontal.step
Hardware/EDA-Files/Source/KNeoPix.3D-Models/NanoBCU_superflat_V00.11_wo_headers.step
Hardware/CAD-Files/Source/Deckel_v0.32.f3d
Hardware/CAD-Files/Source/Gehäuse_v0.32.f3d
Hardware/EDA-Files/Source/KNeoPix.3D-Models/243-212.stp
Hardware/EDA-Files/Source/KNeoPix.3D-Models/GN1_PinHeader_1x07_P254mm_Vertical_585739a4cf5d[4].step
Hardware/EDA-Files/Source/KNeoPix.3D-Models/MicroBCU2_V00.21_wo_headers.step
Hardware/EDA-Files/Source/KNeoPix.3D-Models/NanoBCU_Tantalum_V00.10_wo_headers.step
Hardware/EDA-Files/Source/KNeoPix.3D-Models/NanoBCU_V00.10.step
Hardware/EDA-Files/Source/KNeoPix.3D-Models/NanoBCU_V00.10_wo_headers.step
Hardware/EDA-Files/Source/KNeoPix.3D-Models/NanoBCU_V00.11.step
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

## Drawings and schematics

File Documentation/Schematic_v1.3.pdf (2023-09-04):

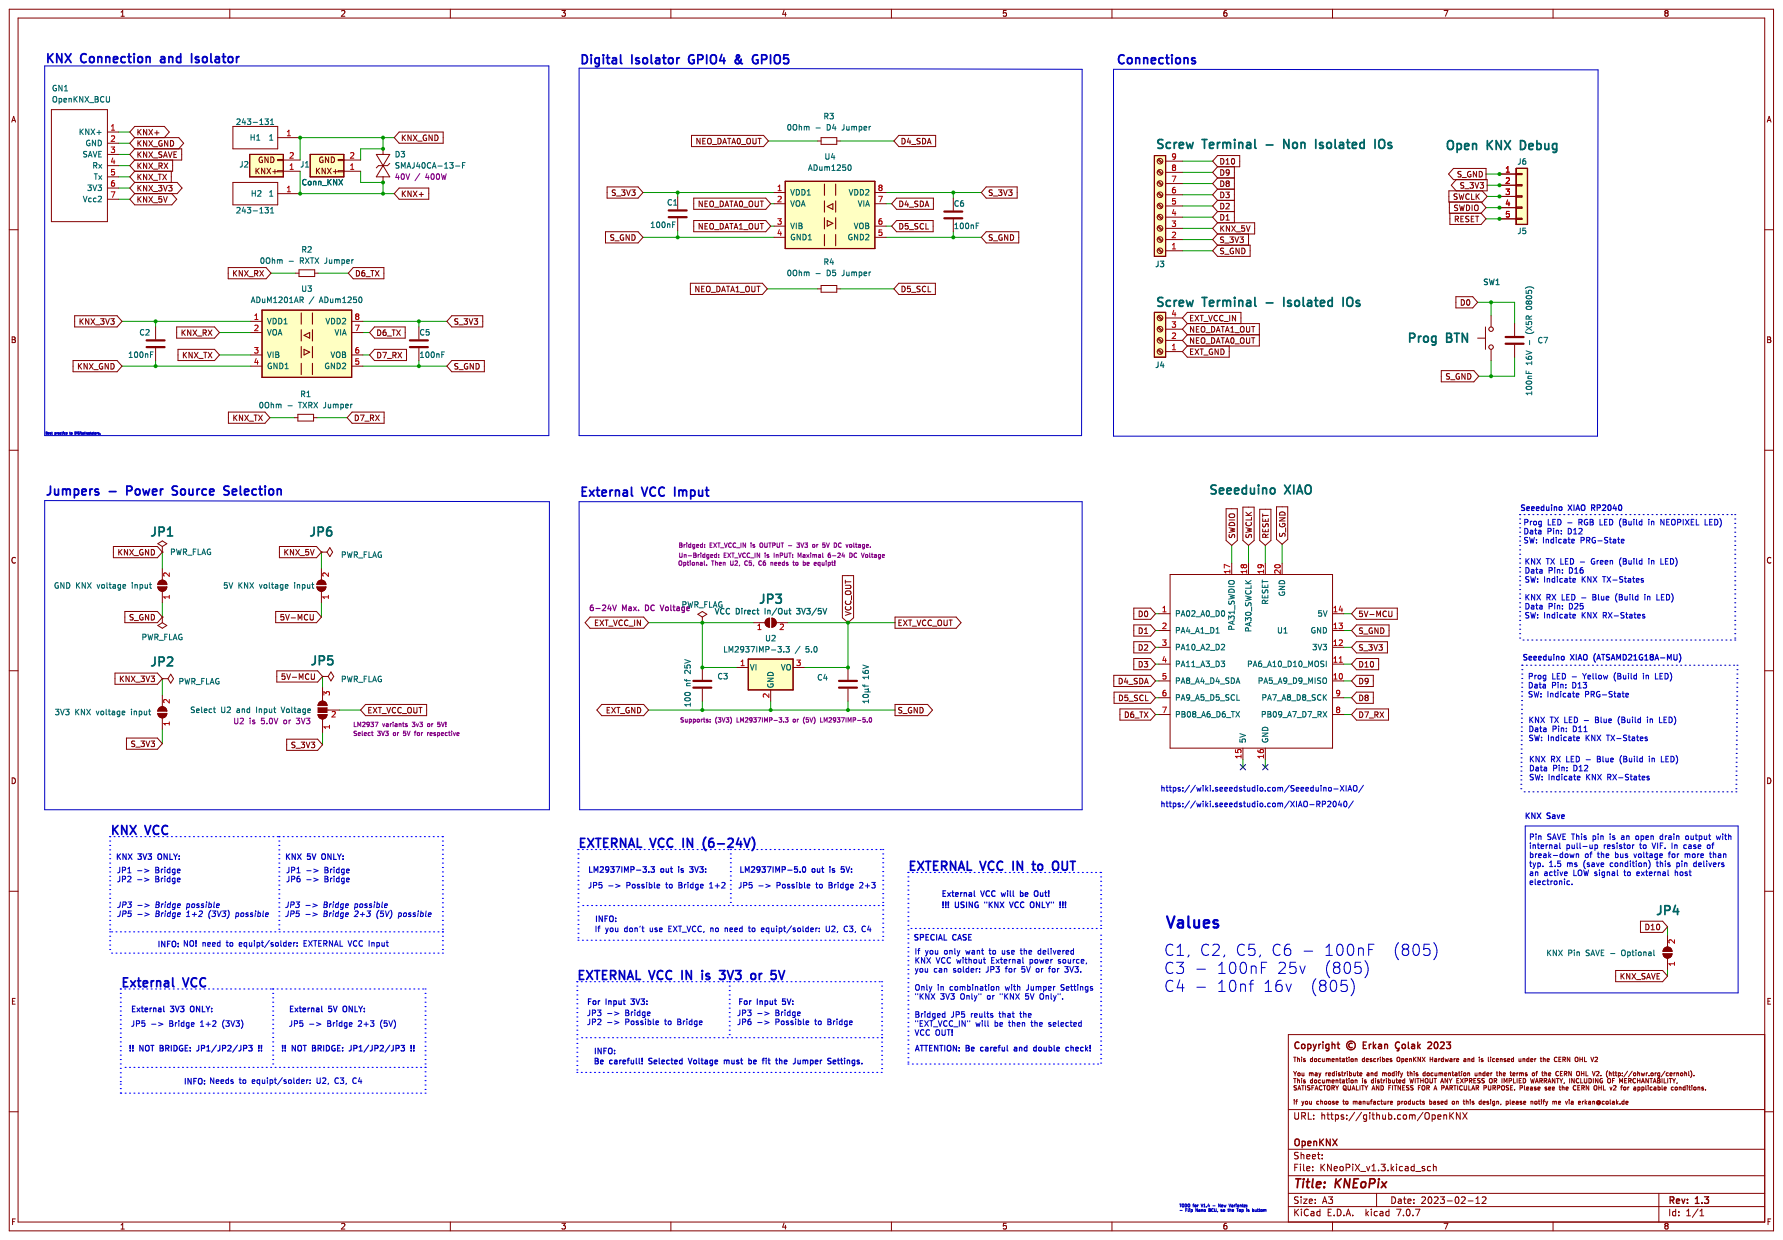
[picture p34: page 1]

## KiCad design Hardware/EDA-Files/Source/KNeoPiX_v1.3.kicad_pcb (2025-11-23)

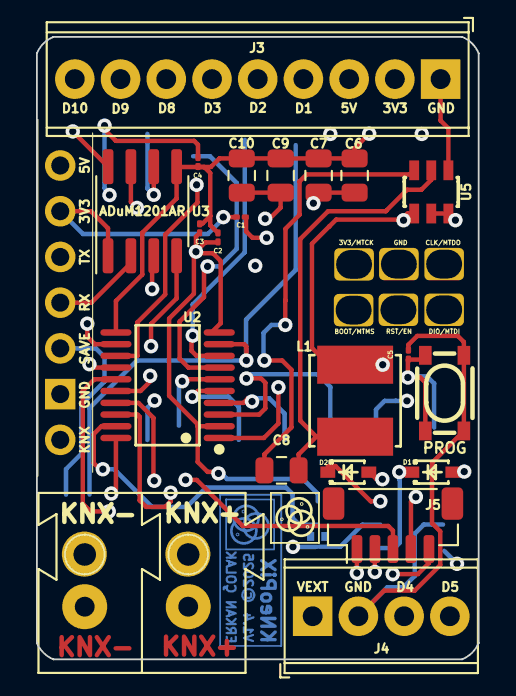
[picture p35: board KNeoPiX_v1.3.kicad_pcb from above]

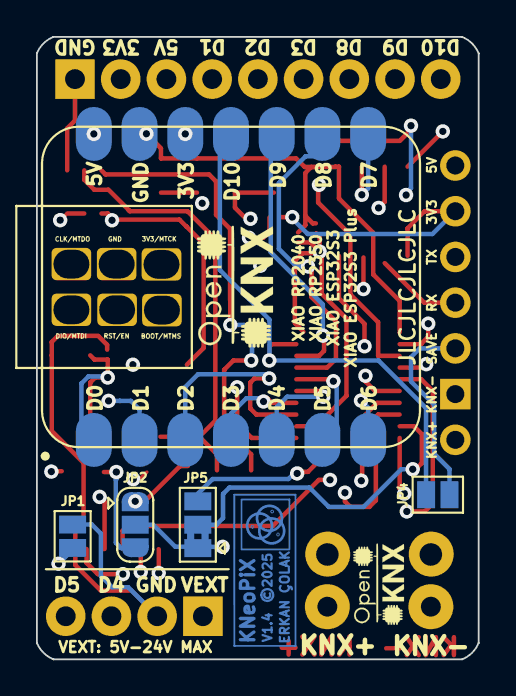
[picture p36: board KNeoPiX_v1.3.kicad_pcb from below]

Board: 4 copper layers, 24.5 x 34.6 mm, 33 parts (8 on the bottom side), 41 nets.

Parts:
C1, C2, C3, C4, C5: 100nF/16v; C_01005_0402Metric
C6, C7: 10uf/50V; C_0805_2012Metric
C8: 100nF/50v; C_0805_2012Metric
C9, C10: 22uf/16V; C_0805_2012Metric
D1, D2: DIODE SCHOTTKY 40V SOD-323HE; SOD-323_L1.7-W1.3-LS2.6-RD-1
GN1: OpenKNX_BCU; NanoBCU_PinSocket_LowProfile
H1, H2: 243-131; 243131
J1: Conn_KNX; KNX_Connector
J2: Conn_KNX; KNX_Connector_Light
J3: Screw Terminal - Isolated IOs; TerminalBlock_Phoenix_MPT-0,5-9-2.54_1x09_P2.54mm_Horizontal
J4: Screw Terminal - Isolated IOs; TerminalBlock_Phoenix_MPT-0,5-4-2.54_1x04_P2.54mm_Horizontal
J5: JST_SH_BM05B-SRSS-TB_1x05-1MP_P1.00mm_Vertical
JP1: KNX GND Input; SolderJumper-2_P1.3mm_Open_Pad1.0x1.5mm
JP2: EXT Input Voltage; SolderJumper-3_P1.3mm_Open_RoundedPad1.0x1.5mm
JP4: KNX Pin SAVE - Optional; SolderJumper-2_P1.3mm_Open_Pad1.0x1.5mm
JP5: SolderJumper_3_Bridged12; SolderJumper-3_P1.3mm_Bridged2Bar12_Pad1.0x1.5mm
L1: CR5040-4R7M; IND-SMD_L5.0-W5.0
REF1: LOGO; OpenKNX_Logo_05x03
REF2: LOGO; OpenKNX_Logo_07x05
REF42: KNeoPix - Logo
SW1: PROG BUTTON; KEY-SMD_4P-L4.2-W3.2-P2.20-LS4.6
U1: Seeeduino XIAO; Seeeduino XIAO-MOUDLE14P-2.54-21X17.8MM-no-15-16-17-18-19-2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
U2: TXS0108EPWR; TSSOP-20_L6.5-W4.4-P0.65-LS6.4-BL
U3: ADUM1250ARZ-RL7 - (ADuM1201AR / ADum1250AR) AR su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; SOIC-8_3.9x4.9mm_P1.27mm
U5: AP63205WU-7; TSOT-26_L2.9-W1.6-P0.95-LS2.8-BL

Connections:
3v3-MCU: C2.1, C3.2, J3.2, JP5.3 (B), U1.12 (3V3), U2.2 (VCCA), U2.10 (OE), U3.8 (VDD2)
3v3/MTCK: J5.2, U1.21 (3V3/MTCK)
5V-MCU: J3.3, JP2.2 (C), JP5.1 (A), U1.14 (5V)
BOOT/MTMS: J5.1, U1.22 (BOOT/MTMS)
CLK/MTDO: J5.3, U1.18 (CLK/MTDO)
D0: C5.1, SW1.1, SW1.2, U1.1 (PA02_A0_D0)
D1: U1.2 (PA4_A1_D1), U2.1 (A1)
D2: U1.3 (PA10_A2_D2), U2.3 (A2)
D3: U1.4 (PA11_A3_D3), U2.4 (A3)
D4: U1.5 (PA8_A4_D4_SDA), U2.5 (A4)
D5: U1.6 (PA9_A5_D5_SCL), U2.6 (A5)
D6_TX: U1.7 (PB08_A6_D6_TX), U3.7 (VIA)
D7_RX: U1.8 (PB09_A7_D7_RX), U3.6 (VOB)
D8: U1.9 (PA7_A8_D8_SCK), U2.7 (A6)
D9: U1.10 (PA5_A9_D9_MISO), U2.8 (A7)
D10: JP4.2 (B), U1.11 (PA6_A10_D10_MOSI), U2.9 (A8)
DIO/MTDI: J5.4, U1.17 (DIO/MTDI)
DL1: J3.4, U2.20 (B1)
DL2: J3.5, U2.18 (B2)
DL3: J3.6, U2.17 (B3)
DL4: J4.3, U2.16 (B4)
DL5: J4.4, U2.15 (B5)
DL8: J3.7, U2.14 (B6)
DL9: J3.8, U2.13 (B7)
DL10: J3.9, U2.12 (B8)
EXT_5V: C9.2, C10.1, D2.2 (A), L1.2, U5.1 (FB)
EXT_GND: C2.2, C3.1, C4.1, C5.2, C6.2, C7.2, C9.1, C10.2, J3.1, J4.2, JP1.1 (A), SW1.3, SW1.4, U1.13 (GND), U1.20 (GND), U2.11 (GND), U3.5 (GND2), U5.4 (GND)
EXT_VCC_IN: C6.1, C7.1, J4.1, U5.2 (EN), U5.3 (VIN)
KNX+: GN1.1 (KNX+), H2.1, J1.1, J2.1
KNX_3V3: C1.1, GN1.6 (3V3), U3.1 (VDD1)
KNX_5V: D1.2 (A), GN1.7 (Vcc2)
KNX_GND: C1.2, GN1.2 (GND), H1.1, J1.2, J2.2, JP1.2 (B), U3.4 (GND1)
KNX_RX: GN1.4 (Rx), U3.2 (VOA)
KNX_SAVE: GN1.3 (SAVE), JP4.1 (A)
KNX_TX: GN1.5 (Tx), U3.3 (VIB)
unnamed: D1.1 (K), JP2.3 (B)
unnamed: D2.1 (K), JP2.1 (A)
unnamed: C8.1, U5.6 (BST)
unnamed: C8.2, L1.1, U5.5 (SW)
RESET/EN: J5.5, U1.19 (RST/EN)
VCC_LS: C4.2, JP5.2 (C), U2.19 (VCCB)

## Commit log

2023-09-03 Initial OpenKNX commit
    [243-131.stp, 243-211--3DModel-STEP-56544.STEP, 243-212.stp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]
2023-09-03 Housing: Printable 3D STL files
    [Case-Deckel_rp2040.stl, Case-Gehäuse_rp2040.stl]
2023-09-04 Initial draft readme & cleanups
    - add Seeed-Studio-XIAO Series SOM datasheet pdf to external documentation
    - add pcb renderings
    - add Schematic_v1.3 pdf
    - cleaned and reorganized Source files
    - add. ESP32-C3 step file
    - fixed kicad pagelayout
    [KNeoPiX_v1.3-B_Silkscreen.dxf, KNeoPiX_v1.3-F_Silkscreen.dxf, KNeoPiX_v1.3-In1_Cu.dxf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]
2023-09-04 Add more rendered images
    - rendered & case assemble images
    - new 3d Model, XIAO-ESP32-C3
    [KNeoPiX_v1.3.kicad_pcb]
2023-09-05 add. CAD Source files
    [Deckel_v0.32.f3d, Deckel_v0.32.step, Gehäuse_v0.32.f3d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]
2023-09-06 Moved KNeoPix step and wrl files CAD-Files/Source folder
    - add. FCStd to CAD-Files/Source
2024-09-18 Update - KiCad 8.0x
    - Fixed Spelling in sch!
    - Ignore Thumbs.db
    [KNeoPiX_v1.3.kicad_pcb, KNeoPiX_v1.3.kicad_sch]
2024-11-09 Corrected IO of SAMD21 LEDs
2024-11-09 Add. NEOPIXEL Power-pin
    NEOPIXEL | GPIO12 / RGB NEOPIXEL (GPIO11 / POWER)
2025-11-22 V1.4 - First Prototype Pre Production - In Review
    [BOM-KNeoPiX_v1.3.csv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]
2025-11-22 Fixed - Prog button GND bug (after Review)
    [KNeoPiX_v1.3.kicad_pcb, KNeoPiX_v1.3.kicad_sch]
2025-11-22 Some DB updates
    [BOM-KNeoPiX_v1.3.csv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]
2025-11-22 AP63205WU-7 (U5) repositioned for better thermal management
    [KNeoPiX_v1.3.kicad_pcb, KNeoPiX_v1.3.kicad_sch]
2025-11-22 Cleaned up tracks.
    [KNeoPiX_v1.3.kicad_pcb]
2025-11-23 Production v1.4
    [BOM-KNeoPiX_v1.4.csv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]
2025-11-23 Rel. prod files
    [BOM-KNeoPiX_v1.4.csv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]

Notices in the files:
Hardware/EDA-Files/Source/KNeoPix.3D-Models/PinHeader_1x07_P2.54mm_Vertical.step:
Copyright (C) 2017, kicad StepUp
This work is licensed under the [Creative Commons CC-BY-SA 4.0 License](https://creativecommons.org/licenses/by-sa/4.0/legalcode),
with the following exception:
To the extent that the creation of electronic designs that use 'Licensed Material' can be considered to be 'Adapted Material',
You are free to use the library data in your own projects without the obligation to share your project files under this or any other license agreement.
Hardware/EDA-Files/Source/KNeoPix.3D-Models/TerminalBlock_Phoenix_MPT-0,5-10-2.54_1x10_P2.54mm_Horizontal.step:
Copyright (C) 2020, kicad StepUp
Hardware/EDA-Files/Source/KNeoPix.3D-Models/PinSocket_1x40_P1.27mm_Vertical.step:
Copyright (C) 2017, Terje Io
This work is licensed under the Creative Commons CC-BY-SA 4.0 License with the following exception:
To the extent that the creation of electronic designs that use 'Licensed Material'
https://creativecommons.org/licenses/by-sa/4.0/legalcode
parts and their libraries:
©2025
